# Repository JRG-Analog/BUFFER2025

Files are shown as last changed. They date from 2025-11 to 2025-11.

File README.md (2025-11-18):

# BUFFER2025
A high current open loop buffer
Board is designed to use 40x40x100mm aluminum heatsink, with 40mm square fan for cooling. 

Description: 
The circuit is an open loop buffer, that is, no feedback. Phase shift induced by load impedance does not affect stability. This was originally built to test PSRR on devices which require an input capacitor, but it can be used for many other experiments.

Performance: 
  IOUT +10/-8A normal; +21A/-15A in High Bias
  BW 60MHz, rl = 0.5Ω, 1VRMS, +8V/-3V;
  ZOUT = 250mΩ normal, 25mΩ in High Bias
  Supply Current 45mA normal, 530mA in High Bias

Usage: 
Connect to power supply with current capability to match expected load. The each supply should be set to 3V more than the expected swing. For example, for a 0V to 5V squarewave use +8V and -3V. Connect the input to a function generator. This is high impedance input, so most function generators will have 2x the expected output voltage. Use short heavy cables to conect to the load.

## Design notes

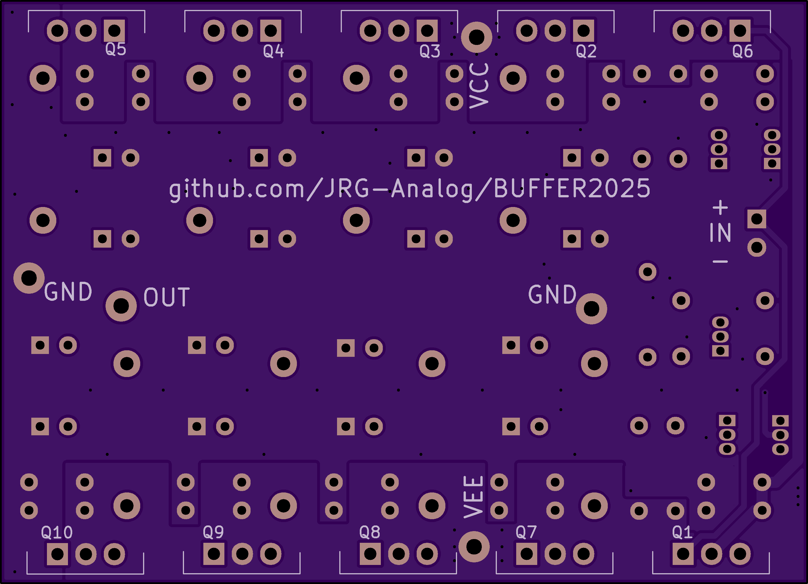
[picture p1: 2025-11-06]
Buffer PCB Bot.png

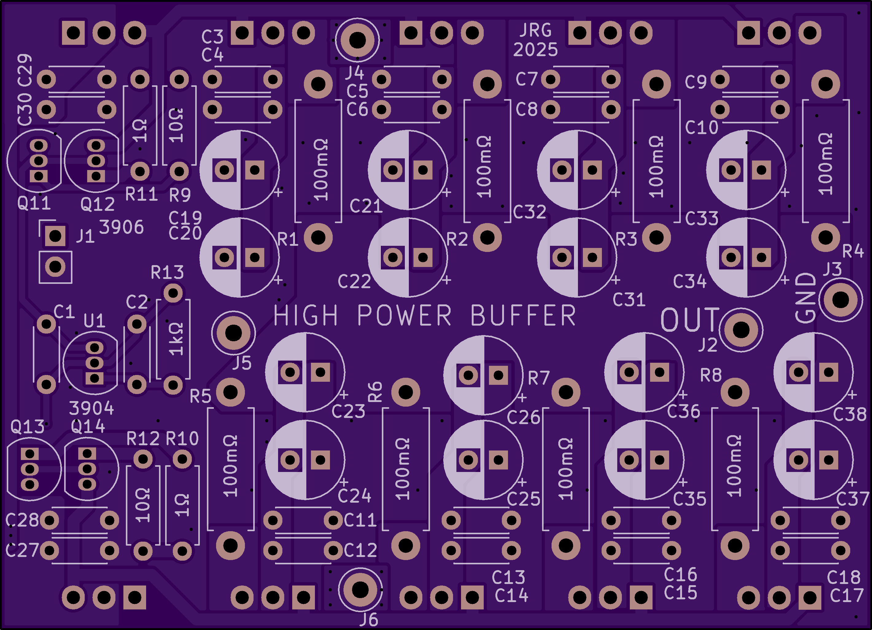
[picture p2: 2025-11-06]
Buffer PCB Top.png

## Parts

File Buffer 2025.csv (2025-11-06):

Reference | Qty | Value | Description | Footprint
C1,C2,C3,C4,C5,C6,C7,C8,C9,C10,C11,C12,C13,C14,C15,C16,C17,C18,C27,C28,C29,C30 | 22 | 100nF | X5R, 50V or better | Capacitor_THT:C_Disc_D4.3mm_W1.9mm_P5.00mm
C19,C20,C21,C22,C23,C24,C25,C26,C31,C32,C33,C34,C35,C36,C37,C38 | 16 | 100µF | 35V, low ESR | Capacitor_THT:CP_Radial_D6.3mm_P2.50mm
J1 | 1 | Conn_Coaxial | Wire to BNC | Connector_PinHeader_2.54mm:PinHeader_1x02_P2.54mm_Vertical
J2,J3,J4,J5,J6 | 5 | ~ | Wire to banana jack | TestPoint:TestPoint_Loop_D3.50mm_Drill1.4mm_Beaded
Q1,Q2,Q3,Q4,Q5 | 5 | C6144 | On Semi | AA JG Lib Footprints Library:TO-220-3_Vertical_FP
Q6,Q7,Q8,Q9,Q10 | 5 | A2222 | On Semi | AA JG Lib Footprints Library:TO-220-3_Vertical_FP
Q11,Q12 | 2 | 2N3906 |  | Package_TO_SOT_THT:TO-92_Inline
Q13,Q14 | 2 | 2N3904 |  | Package_TO_SOT_THT:TO-92_Inline
R1,R2,R3,R4,R5,R6,R7,R8 | 8 | 100m? | 1W, 5% or better | Resistor_THT:R_Axial_DIN0411_L9.9mm_D3.6mm_P12.70mm_Horizontal
R9,R10 | 2 | 10? | 1/4W, 5% or better | Resistor_THT:R_Axial_DIN0207_L6.3mm_D2.5mm_P7.62mm_Horizontal
R11,R12 | 2 | 1? | 1/4W, 5% or better | Resistor_THT:R_Axial_DIN0207_L6.3mm_D2.5mm_P7.62mm_Horizontal
R13 | 1 | 1k? | 1/4W, 5% or better | Resistor_THT:R_Axial_DIN0207_L6.3mm_D2.5mm_P7.62mm_Horizontal
U1 | 1 | L78L05 |  | Package_TO_SOT_THT:TO-92_Inline

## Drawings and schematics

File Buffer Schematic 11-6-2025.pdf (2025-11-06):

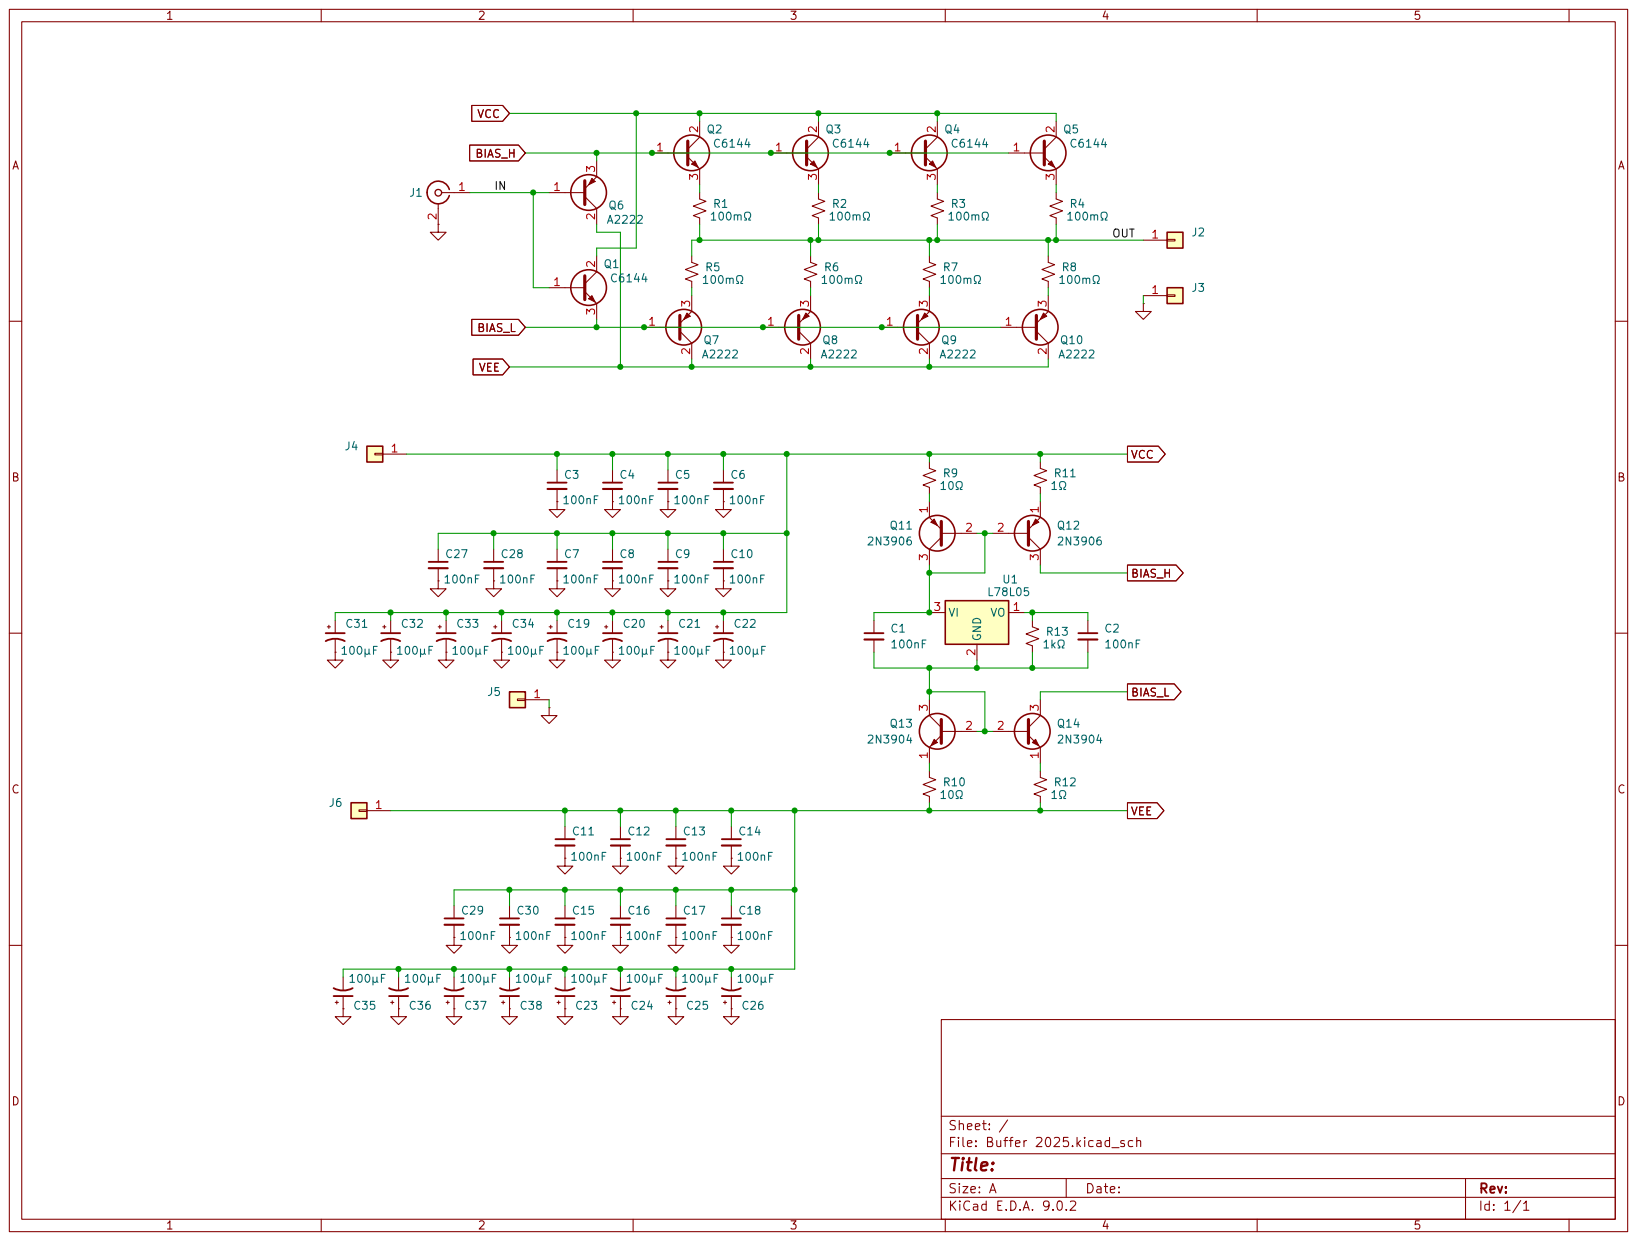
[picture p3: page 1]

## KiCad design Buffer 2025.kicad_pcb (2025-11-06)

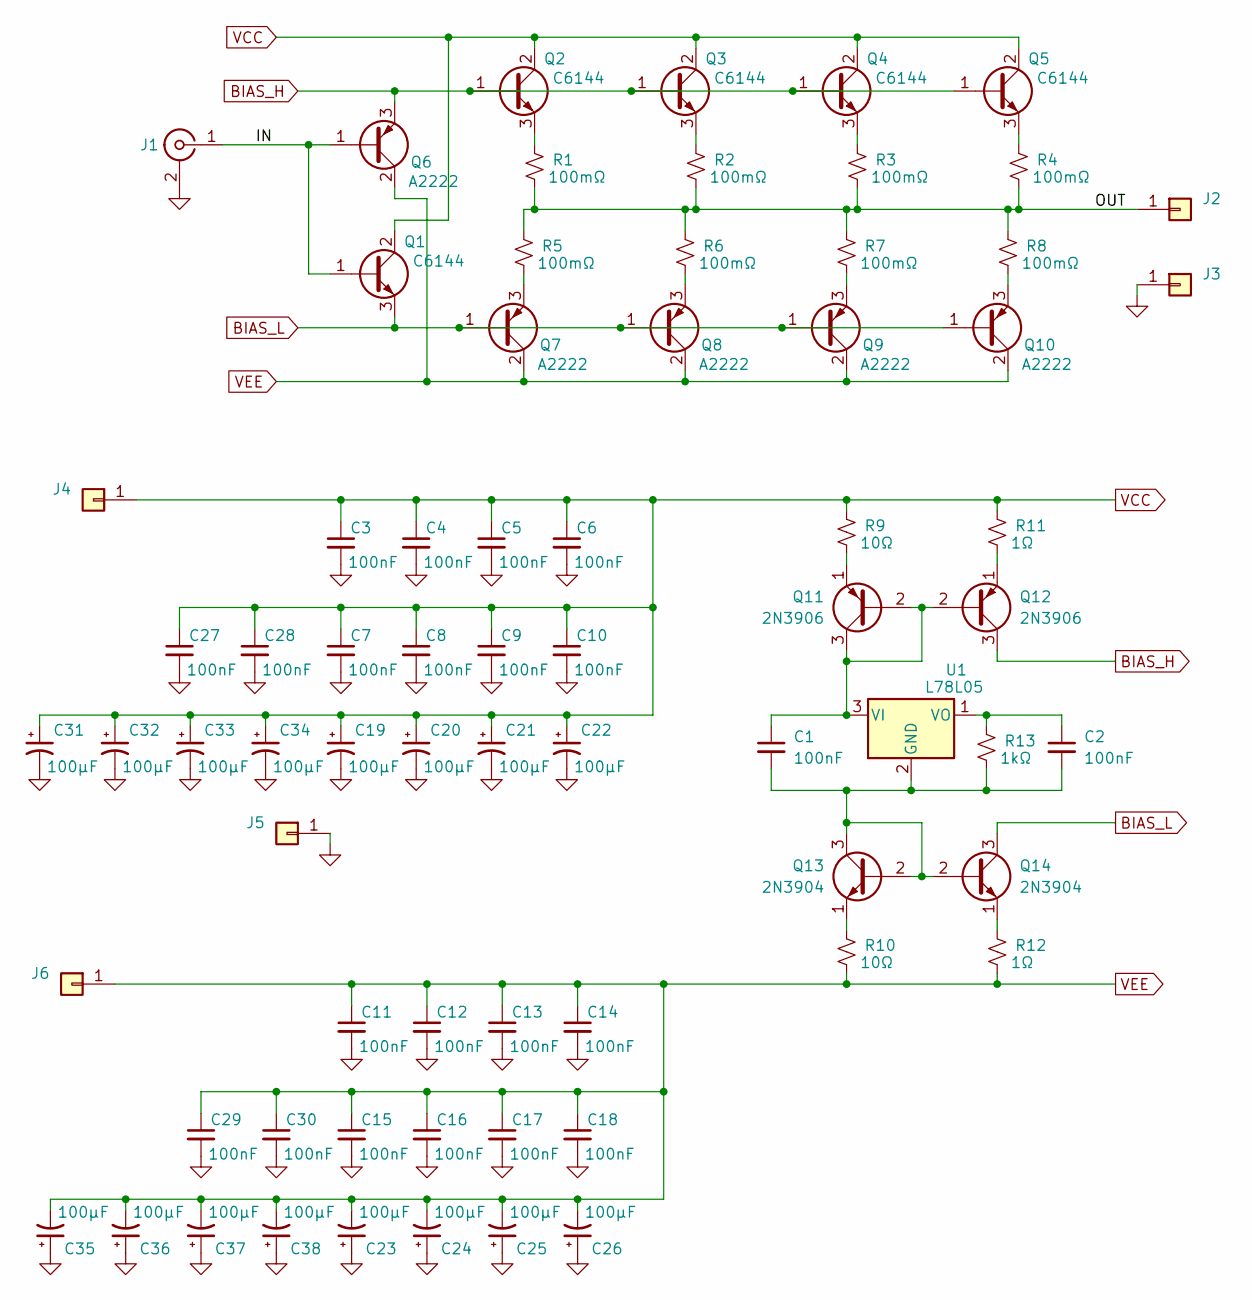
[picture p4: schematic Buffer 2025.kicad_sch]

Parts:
C1, C2, C3, C4, C5, C6, C7, C8, C9, C10, C11, C12, C13, C14, C15, C16, C17, C18, C27, C28, C29, C30: 100nF; C_Disc_D4.3mm_W1.9mm_P5.00mm
C19, C20, C21, C22, C23, C24, C25, C26, C31, C32, C33, C34, C35, C36, C37, C38: 100µF; CP_Radial_D6.3mm_P2.50mm
J1: Conn_Coaxial; PinHeader_1x02_P2.54mm_Vertical
J2, J3, J4, J5, J6: TestPoint_Loop_D3.50mm_Drill1.4mm_Beaded
Q1, Q2, Q3, Q4, Q5: C6144; TO-220-3_Vertical_FP
Q6, Q7, Q8, Q9, Q10: A2222; TO-220-3_Vertical_FP
Q11, Q12: 2N3906; TO-92_Inline
Q13, Q14: 2N3904; TO-92_Inline
R1, R2, R3, R4, R5, R6, R7, R8: 100mΩ; R_Axial_DIN0411_L9.9mm_D3.6mm_P12.70mm_Horizontal
R9, R10: 10Ω; R_Axial_DIN0207_L6.3mm_D2.5mm_P7.62mm_Horizontal
R11, R12: 1Ω; R_Axial_DIN0207_L6.3mm_D2.5mm_P7.62mm_Horizontal
R13: 1kΩ; R_Axial_DIN0207_L6.3mm_D2.5mm_P7.62mm_Horizontal
U1: L78L05; TO-92_Inline

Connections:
/IN: J1.1 (In), Q1.1 (B), Q6.1 (B)
/OUT: J2.1, R1.2, R2.2, R3.2, R4.2, R5.1, R6.1, R7.1, R8.1
BIAS_H: Q2.1 (B), Q3.1 (B), Q4.1 (B), Q5.1 (B), Q6.3 (E), Q12.3 (C)
BIAS_L: Q1.3 (E), Q7.1 (B), Q8.1 (B), Q9.1 (B), Q10.1 (B), Q14.3 (C)
GND: C3.2, C4.2, C5.2, C6.2, C7.2, C8.2, C9.2, C10.2, C11.2, C12.2, C13.2, C14.2, C15.2, C16.2, C17.2, C18.2, C19.2, C20.2, C21.2, C22.2, C23.1, C24.1, C25.1, C26.1, C27.2, C28.2, C29.2, C30.2, C31.2, C32.2, C33.2, C34.2, C35.1, C36.1, C37.1, C38.1, J1.2 (Ext), J3.1, J5.1
unnamed: Q2.3 (E), R1.1
unnamed: Q3.3 (E), R2.1
unnamed: Q4.3 (E), R3.1
unnamed: Q5.3 (E), R4.1
unnamed: Q7.3 (E), R5.2
unnamed: Q8.3 (E), R6.2
unnamed: Q9.3 (E), R7.2
unnamed: Q10.3 (E), R8.2
unnamed: C1.1, Q11.2 (B), Q11.3 (C), Q12.2 (B), U1.3 (VI)
unnamed: Q11.1 (E), R9.2
unnamed: Q12.1 (E), R11.2
unnamed: C1.2, C2.2, Q13.2 (B), Q13.3 (C), Q14.2 (B), R13.2, U1.2 (GND)
unnamed: Q13.1 (E), R10.1
unnamed: Q14.1 (E), R12.1
unnamed: C2.1, R13.1, U1.1 (VO)
VCC: C3.1, C4.1, C5.1, C6.1, C7.1, C8.1, C9.1, C10.1, C19.1, C20.1, C21.1, C22.1, C27.1, C28.1, C31.1, C32.1, C33.1, C34.1, J4.1, Q1.2 (C), Q2.2 (C), Q3.2 (C), Q4.2 (C), Q5.2 (C), R9.1, R11.1
VEE: C11.1, C12.1, C13.1, C14.1, C15.1, C16.1, C17.1, C18.1, C23.2, C24.2, C25.2, C26.2, C29.1, C30.1, C35.2, C36.2, C37.2, C38.2, J6.1, Q6.2 (C), Q7.2 (C), Q8.2 (C), Q9.2 (C), Q10.2 (C), R10.2, R12.2

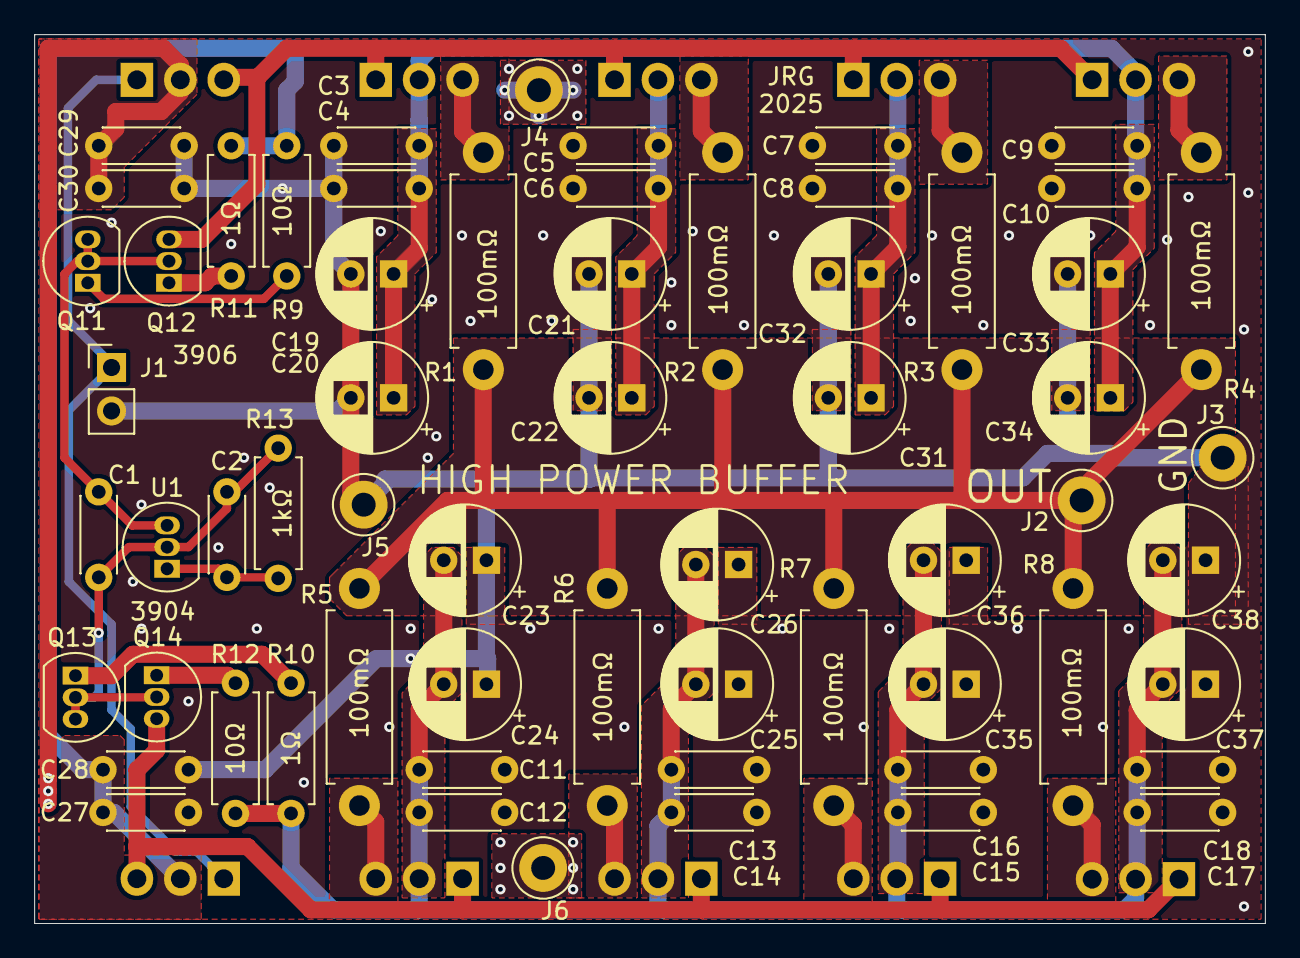
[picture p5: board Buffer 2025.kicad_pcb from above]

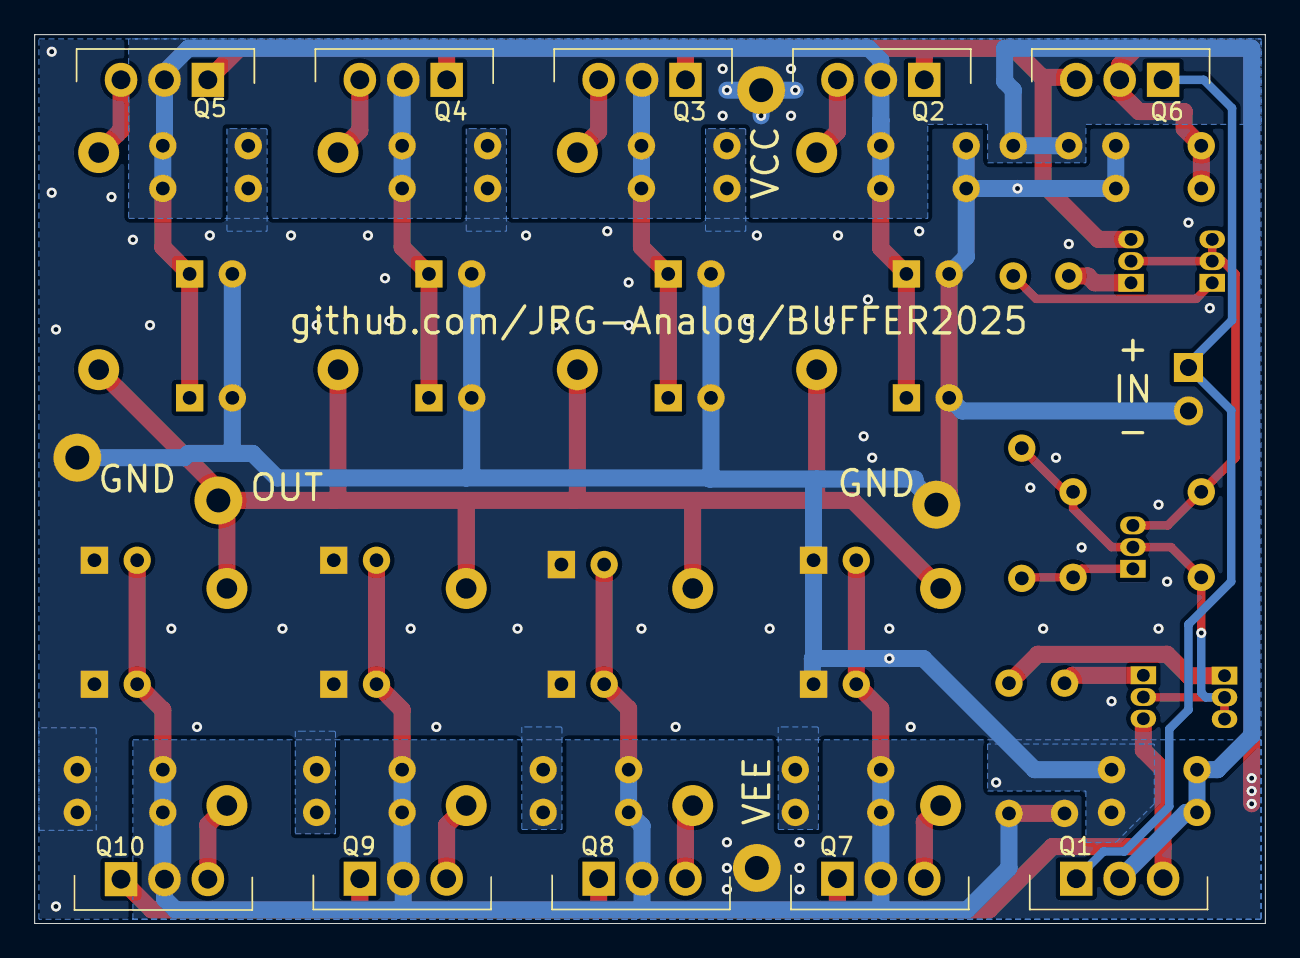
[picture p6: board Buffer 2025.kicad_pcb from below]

Board: 2 copper layers, 72.0 x 52.0 mm, 72 parts (10 on the bottom side), 22 nets.
